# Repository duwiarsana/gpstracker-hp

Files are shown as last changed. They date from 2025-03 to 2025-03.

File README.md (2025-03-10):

# GPS GPRS SMS Tracker

Proyek ini menggunakan **modul GPS dan GPRS (GSM)** secara terpisah untuk mengirimkan koordinat lokasi via SMS ketika menerima perintah dari pengguna. Koding ini dibuat khusus untuk PCB yang sudah dicetak dalam proyek ini.

## 📌 Deskripsi Proyek

Kode ini bekerja dengan membaca data dari modul **GPS** dan mengirimkan koordinat melalui **modul GPRS (GSM)** dalam bentuk link Google Maps. Saat perangkat menerima SMS dengan kata kunci **"LOKASI"**, maka akan membalas dengan tautan lokasi GPS terbaru.

Selain mengirimkan lokasi melalui SMS, proyek ini juga memiliki fitur **panggilan suara**. Jika nomor yang terhubung dengan modul GSM melakukan panggilan ke perangkat ini, maka panggilan akan **otomatis diangkat pada dering ketiga**.

Proyek ini masih berbasis SMS, tetapi jika ingin mengembangkan sistem dengan mengirim data ke **server atau internet**, bisa dilakukan update coding dengan menggunakan **basis data GPRS**.

## 🛠️ Hardware yang Digunakan

- **Mikrokontroler**: Arduino (contoh: Arduino Uno, Nano, atau lainnya)
- **Modul GPS**: Neo-6M atau kompatibel
- **Modul GSM/GPRS**: SIM800L atau SIM900
- **PCB Custom**: Koding ini dibuat untuk PCB khusus yang sudah dirancang agar sesuai dengan proyek ini
- **Kartu SIM** dengan pulsa untuk mengirim SMS dan melakukan panggilan

## 🖇️ **Koneksi Hardware** (Jika Menggunakan Arduino dengan Modul GPS & GSM Terpisah)

Jika kamu menggunakan Arduino tanpa PCB khusus, pastikan koneksi berikut:

### **Modul GPS (Neo-6M)**

| GPS Pin | Arduino Pin |
| --- | --- |
| VCC | 5V |
| GND | GND |
| TX | D3 |
| RX | D2 |

### **Modul GSM (SIM800L/SIM900)**

| GSM Pin | Arduino Pin |
| --- | --- |
| VCC | 5V (Gunakan regulator 4.2V jika perlu) |
| GND | GND |
| TX | D5 |
| RX | D4 |

> **Catatan:** Jika menggunakan PCB khusus yang sudah dicetak, koneksi sudah diatur secara langsung dalam desain PCB, jadi tidak perlu kabel tambahan.

## 🔧 Library yang Digunakan

Sebelum meng-compile kode, pastikan kamu sudah menginstal library berikut di **Arduino IDE**:

- **[TinyGPS++](https://github.com/mikalhart/TinyGPSPlus)** → Untuk membaca data dari GPS
- **SoftwareSerial** (bawaan Arduino) → Untuk komunikasi serial dengan modul GSM & GPS

## ⚙️ Cara Kerja

1. **Perangkat menyala** dan mulai membaca data GPS.
2. Saat menerima SMS dengan isi **"LOKASI"**, perangkat akan mengambil data koordinat dari GPS.
3. Data latitude dan longitude akan diubah menjadi link Google Maps.
4. SMS akan dikirim kembali ke pengirim dengan format: https://maps.google.com/?q=latitude,longitude
5. Nomor pengirim SMS akan disimpan sementara untuk membalas otomatis.
6. Setelah mengirim SMS, perangkat menghapus pesan yang diterima agar memori tidak penuh.
7. Jika ada **panggilan masuk**, perangkat akan **otomatis mengangkat pada dering ketiga**.

## 📌 Cara Menggunakan

1. **Siapkan PCB yang sudah dirakit** dengan Arduino dan modul GPS/GSM.
2. **Masukkan kartu SIM ke modul GSM** (pastikan memiliki pulsa atau paket SMS).
3. **Upload kode ke Arduino** menggunakan Arduino IDE.
4. **Kirim SMS berisi "LOKASI"** ke nomor yang ada di modul GSM.
5. **Perangkat akan membalas dengan link lokasi** berdasarkan data dari modul GPS.
6. **Lakukan panggilan ke nomor SIM pada modul GSM**, dan perangkat akan **mengangkat otomatis pada dering ketiga**.

## 🔥 Troubleshooting

Jika tidak mendapatkan SMS balasan atau koordinat tidak muncul:

- **Cek power supply modul GSM** (SIM800L biasanya butuh minimal 2A agar stabil).
- **Pastikan modul GPS mendapatkan sinyal satelit** (gunakan di luar ruangan untuk tes awal).
- **Gunakan serial monitor** di Arduino IDE untuk melihat output debug.

## 📜 Lisensi

Proyek ini menggunakan lisensi MIT, yang berarti bebas digunakan, dimodifikasi, dan didistribusikan.

---

🚀 Selamat mencoba! Jika ada pertanyaan atau ingin menggunakan PCB khusus ini, silakan hubungi saya.

## 💖 Dukung Pengembangan Proyek Ini

Jika kamu merasa proyek ini bermanfaat dan ingin mendukung pengembangan lebih lanjut, kamu bisa memberikan **donasi melalui Saweria**:

🔗 [https://saweria.co/duwiarsana](https://saweria.co/duwiarsana)  

Terima kasih atas dukungannya! 🤗

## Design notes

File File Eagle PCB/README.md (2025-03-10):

# README FILE EAGLE PCB GPS Tracker Mini

## Deskripsi Proyek
GPS Tracker Mini adalah proyek pelacak GPS berbasis **ATmega328P**, **SIM800C**, dan **Quectel L80 GNSS**. Proyek ini memungkinkan pelacakan lokasi secara real-time dengan komunikasi GSM/GPRS.

### Fitur Utama:
- **Pelacakan GPS:** Menggunakan modul **Quectel L80** untuk mendapatkan koordinat lokasi secara akurat.
- **Koneksi GSM:** Memanfaatkan modul **SIM800C** untuk mengirimkan data lokasi melalui SMS atau server berbasis GPRS.
- **Microcontroller ATmega328P:** Sebagai pusat kendali dari perangkat.
- **Slot MicroSD:** Untuk menyimpan log data lokasi jika koneksi tidak tersedia.
- **Konektor U.FL:** Untuk penggunaan antena eksternal pada modul GSM.

## Skema dan Desain PCB
Desain perangkat ini dibuat menggunakan **Eagle PCB** dan terdiri dari dua file utama:
- **Schematic:** [`GPS TRACKER MINI.sch`](./GPS%20TRACKER%20MINI.sch)
- **PCB Layout:** [`GPS TRACKER MINI.brd`](./GPS%20TRACKER%20MINI.brd)

## Skema Kalau Pakai Arduino Uno dan GPS NEO
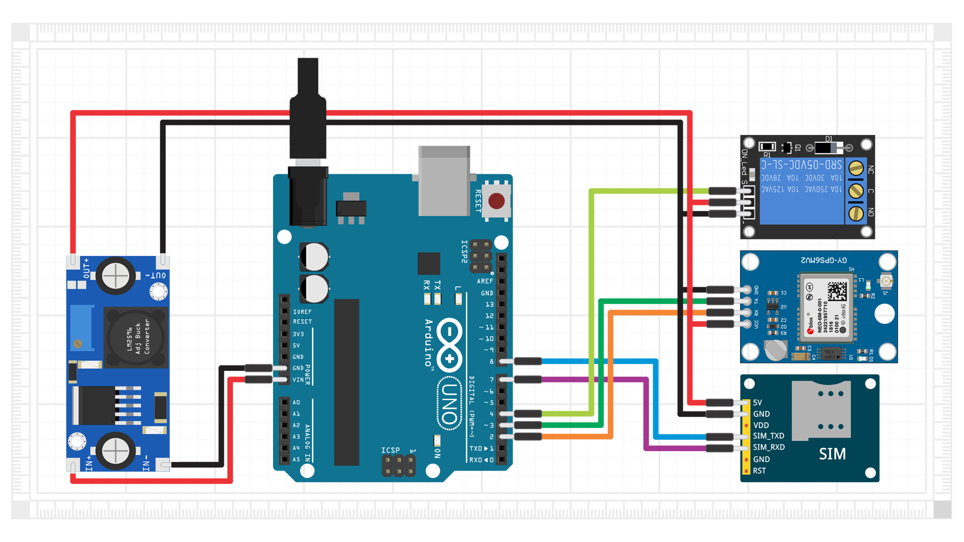
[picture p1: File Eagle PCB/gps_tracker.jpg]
GPS Tracker


## Bill of Materials (BOM)
Berikut adalah daftar komponen utama yang digunakan dalam proyek ini:

| Qty | Value | Device | Package | Parts |
|----|---|---|---|---|
| 1  | ATMEGA328P-MU | ATMEGA328P-MU | QFN-32 | U1 |
| 1  | SIM800C | SIM800C | LCC-42 | U2 |
| 1  | L80_GNSS_MODULE | L80 GNSS Module | Custom | U3 |
| 1  | 4050D | Hex Buffer | SO16 | IC1 |
| 1  | LP298-33 | LDO Regulator 3.3V | SOT23-5L | IC2 |
| 1  | MICROSD | MicroSD Card Slot | MICROSD | X1 |
| 1  | ZD-SOD123 | 5.1V Zener Diode | SOD123 | ZD1 |
| 4  | 0.1uF | Capacitor | C0603 | C3, C15, C19, C21 |
| 2  | 100uF | Capacitor | B/3528-21R | C4, C5 |
| 1  | 10K | Resistor | R0603 | R1 |
| 1  | CSTCE16M0V53MU | Ceramic Resonator 16MHz | CSTCE16M0V53 | Y1 |
| 1  | SIM8051-6-0-14-01-X | Nano SIM Card Connector | SMT | J1 |
| 1  | CON-HIROSE-COAXIAL-U.FL | U.FL Connector | SMT | GSM |
| 1  | LED (Red) | Indicator | LED0805 | ACT |
| 1  | LED (Blue) | Indicator | LED0805 | LED4 |

## Instalasi dan Penggunaan
1. **Flash Firmware** ke ATmega328P menggunakan Arduino IDE atau PlatformIO.
2. **Sambungkan Antena** ke konektor U.FL untuk sinyal GSM lebih baik.
3. **Masukkan Kartu SIM** dan pastikan memiliki paket data aktif.
4. **Gunakan Software** untuk membaca koordinat GPS yang dikirim via SMS atau HTTP POST.

## Pemesanan PCB & Donasi
Jika kamu ingin membeli PCB dari proyek ini atau mendukung pengembangannya, silakan hubungi saya melalui WhatsApp:  
📲 **[085738244251](https://wa.me/6285738244251)**

Atau bisa juga berdonasi melalui:  


## Lisensi
Proyek ini berlisensi **MIT License**, artinya bebas digunakan dan dimodifikasi, namun tetap mencantumkan atribusi kepada pembuat asli.

---
Jika ada pertanyaan atau saran, jangan ragu untuk menghubungi saya melalui GitHub atau media sosial lainnya!

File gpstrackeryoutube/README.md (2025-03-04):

# GPS GPRS SMS Tracker - Arduino Code

Dokumentasi ini menjelaskan bagaimana menggunakan koding dalam folder ini untuk proyek **GPS GPRS SMS Tracker**. Koding ini dirancang untuk bekerja dengan **modul GPS dan GSM (GPRS) secara terpisah**, serta dibuat khusus untuk PCB yang sudah dirancang dalam proyek ini.

## 📌 Persyaratan Software

Untuk menjalankan koding ini, kamu memerlukan software berikut:

1. **[Arduino IDE](https://www.arduino.cc/en/software)** - Untuk mengedit dan mengupload kode ke mikrokontroler.
2. **Driver CH340/CP2102** (jika menggunakan Arduino clone) - Sesuaikan dengan jenis mikrokontroler yang digunakan.
3. **Library Arduino yang dibutuhkan**:
   - [TinyGPS++](https://github.com/mikalhart/TinyGPSPlus) → Untuk membaca data GPS.
   - SoftwareSerial (bawaan Arduino) → Untuk komunikasi serial dengan modul GSM & GPS.

## ⚙️ Cara Menggunakan Koding Ini

1. **Buka Arduino IDE** dan pastikan board yang digunakan sudah terdeteksi.
2. **Instal Library yang Dibutuhkan**
   - Buka **Sketch** > **Include Library** > **Manage Libraries**
   - Cari dan instal **TinyGPS++**
3. **Hubungkan Arduino ke PC** menggunakan kabel USB.
4. **Sesuaikan Koneksi Hardware** jika tidak menggunakan PCB custom (lihat tabel koneksi di README utama).
5. **Upload kode ke Arduino**:
   - Pilih board yang sesuai (**Tools > Board > Arduino Uno/Nano/etc**).
   - Pilih port serial yang sesuai (**Tools > Port > COMx**).
   - Klik tombol **Upload** (ikon panah kanan di Arduino IDE).
6. **Buka Serial Monitor** (Baudrate 9600) untuk melihat log proses komunikasi.
7. **Uji dengan SMS**
   - Kirim SMS berisi **"LOKASI"** ke nomor kartu SIM yang ada di modul GSM.
   - Jika berhasil, akan menerima SMS balasan berupa link Google Maps.
8. **Uji dengan Panggilan**
   - Lakukan panggilan ke nomor SIM dalam modul GSM.
   - Perangkat akan **mengangkat otomatis pada dering ketiga**.

## 🔥 Troubleshooting

- **GPS tidak mendapatkan sinyal?**
  - Pastikan antena GPS terpasang dengan benar.
  - Coba uji di area terbuka untuk mendapatkan sinyal lebih cepat.

- **GSM tidak mengirim atau menerima SMS?**
  - Cek apakah kartu SIM memiliki pulsa atau paket SMS aktif.
  - Pastikan koneksi antara Arduino dan modul GSM sudah benar.

- **Tidak bisa upload kode?**
  - Cek apakah driver CH340/CP2102 sudah terinstal.
  - Coba gunakan kabel USB yang berbeda.

## 📜 Lisensi

Kode ini menggunakan lisensi MIT, artinya bebas digunakan dan dimodifikasi. Jika kamu ingin menggunakan atau mengembangkan proyek ini lebih lanjut, silakan!

🚀 Selamat mencoba!

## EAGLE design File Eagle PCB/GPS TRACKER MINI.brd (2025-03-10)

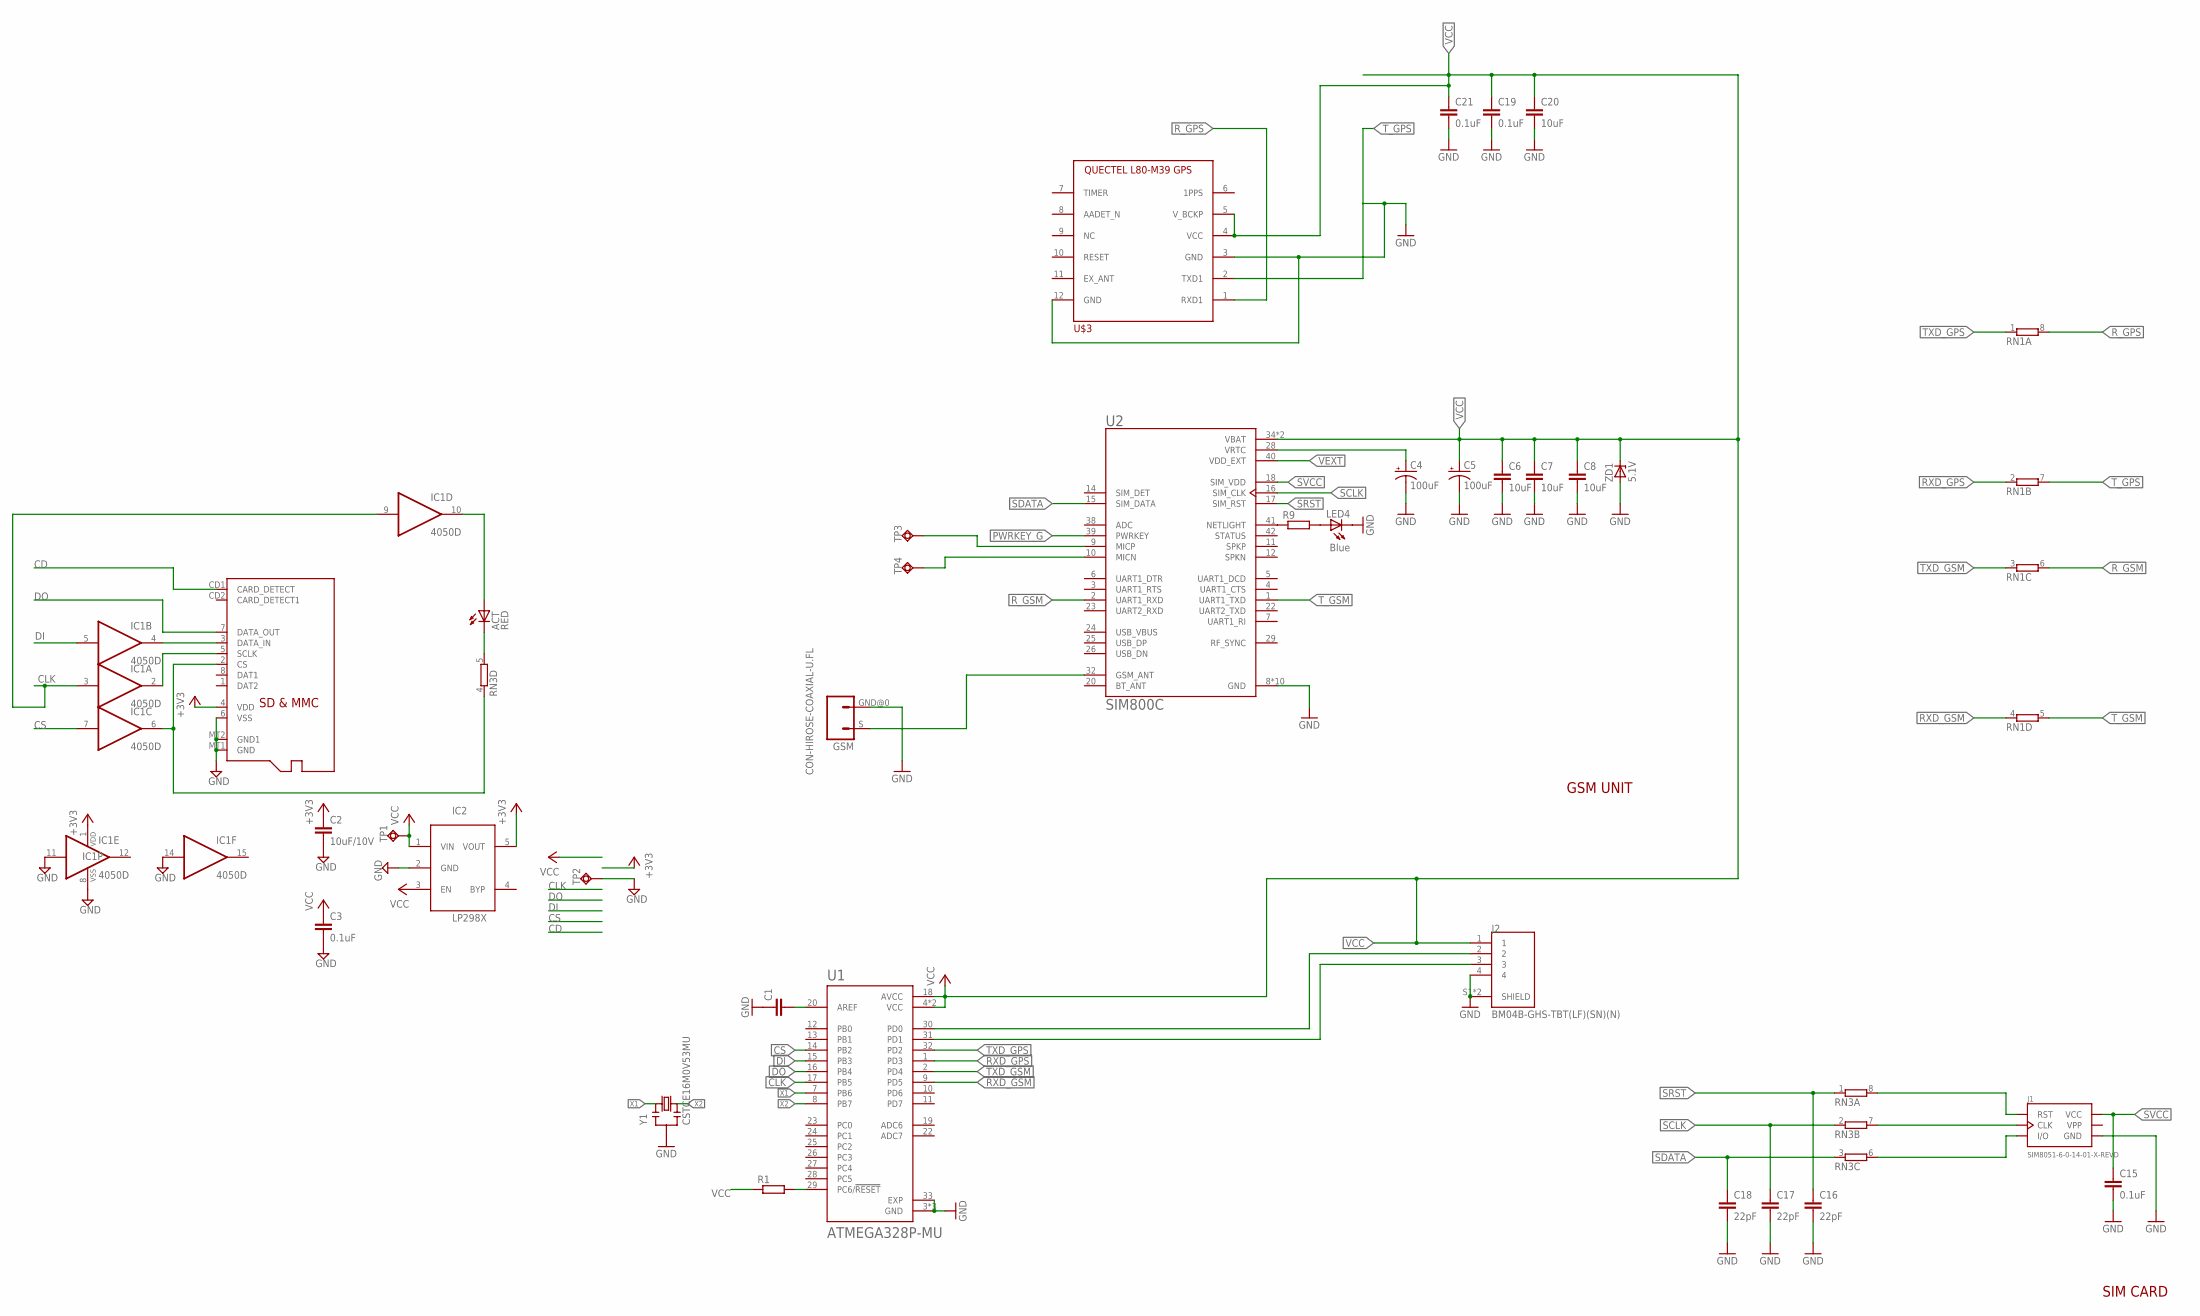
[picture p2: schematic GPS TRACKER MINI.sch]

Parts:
ACT: RED; CHIP-LED0805
C1: C-EUC0603K; C0603K
C2: 10uF/10V; C0603
C3, C15, C19, C21: 0.1uF; C0603
C4, C5: 100uF; B/3528-21R
C6, C7, C8, C20: 10uF; C0603
C16, C17, C18: 22pF; C0603
GSM: CON-HIROSE-COAXIAL-U.FL; CON-U.FL
IC1: 4050D; SO16
IC2: LP298XS; SOT23-5L
J1: SIM8051-6-0-14-01-X-REVD; GCT_SIM8051-6-0-14-01-X-REVD
J2: BM04B-GHS-TBT(LF)(SN)(N); JST_BM04B-GHS-TBT(LF)(SN)(N)
LED4: Blue; CHIP-LED0805
R1, R9: R-EU_R0603; R0603
RN1, RN3: 4R-N0603-ARC; 0603-ARC
TP1, TP2: TPSQTP20R; TP20R
TP3, TP4: TPSQTP14R; TP14R
U1: ATMEGA328P-MU; QFN50P500X500X100-33N
U2: SIM800C; LCC110P1570X1760X250-42N
U$3: L80_GNSS_MODULE; L80_PACKAGE
X1: MICROSD
Y1: CSTCE16M0V53MU; CSTCE16M0V53
ZD1: 5.1V; SOD123

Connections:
+3V3: C2.1, IC1.1 (VDD), IC2.5 (VOUT), X1.4 (VDD)
CD: X1.CD1 (CARD_DETECT)
CLK: IC1.3 (I), IC1.9 (I), U1.17 (PB5)
CS: IC1.7 (I), U1.14 (PB2)
DI: IC1.5 (I), U1.15 (PB3)
DO: U1.16 (PB4), X1.7 (DATA_OUT)
GND: C1.1, C2.2, C3.2, C4.-, C5.-, C6.2, C7.2, C8.2, C15.2, C16.2, C17.2, C18.2, C19.2, C20.2, C21.2, GSM.GND@0 (2), IC1.8 (VSS), IC1.11 (I), IC1.14 (I), IC2.2 (GND), J1.C5 (GND), J2.4, J2.S1 (SHIELD), J2.S2 (SHIELD), LED4.C, TP2.TP, U1.3 (GND), U1.5 (GND), U1.21 (GND), U1.33 (EXP), U2.8 (GND), U2.13 (GND), U2.19 (GND), U2.21 (GND), U2.27 (GND), U2.30 (GND), U2.31 (GND), U2.33 (GND), U2.36 (GND), U2.37 (GND), U$3.3 (GND), U$3.12 (GND), X1.6 (VSS), X1.MT1 (GND), X1.MT2 (GND1), Y1.2, ZD1.A
unnamed: ACT.A, IC1.10 (O)
unnamed: C1.2, U1.20 (AREF)
unnamed: IC1.2 (O), X1.5 (SCLK)
unnamed: IC1.6 (O), RN3.4 (1), X1.2 (CS)
unnamed: ACT.C, RN3.5 (2)
unnamed: IC1.4 (O), X1.3 (DATA_IN)
unnamed: R9.1, U2.41 (NETLIGHT)
unnamed: LED4.A, R9.2
unnamed: J2.2, U1.30 (PD0)
unnamed: J2.3, U1.31 (PD1)
unnamed: TP3.TP, U2.9 (MICP)
unnamed: TP4.TP, U2.10 (MICN)
unnamed: R1.2, U1.29 (PC6/!RESET)
unnamed: C4.+, U2.28 (VRTC)
unnamed: GSM.S (1), U2.32 (GSM_ANT)
unnamed: J1.C2 (RST), RN3.8 (2)
unnamed: J1.C3 (CLK), RN3.7 (2)
unnamed: J1.C7 (I/O), RN3.6 (2)
PWRKEY_G: U2.39 (PWRKEY)
RXD_GPS: RN1.2 (1), U1.1 (PD3)
RXD_GSM: RN1.4 (1), U1.9 (PD5)
R_GPS: RN1.8 (2), U$3.1 (RXD1)
R_GSM: RN1.6 (2), U2.2 (UART1_RXD)
SCLK: C17.1, RN3.2 (1), U2.16 (SIM_CLK)
SDATA: C18.1, RN3.3 (1), U2.15 (SIM_DATA)
SRST: C16.1, RN3.1, U2.17 (SIM_RST)
SVCC: C15.1, J1.C1 (VCC), U2.18 (SIM_VDD)
TXD_GPS: RN1.1, U1.32 (PD2)
TXD_GSM: RN1.3 (1), U1.2 (PD4)
T_GPS: RN1.7 (2), U$3.2 (TXD1)
T_GSM: RN1.5 (2), U2.1 (UART1_TXD)
VCC: C3.1, C5.+, C6.1, C7.1, C8.1, C19.1, C20.1, C21.1, IC2.1 (VIN), IC2.3 (EN), J2.1, R1.1, TP1.TP, U1.4 (VCC), U1.6 (VCC), U1.18 (AVCC), U2.34 (VBAT), U2.35 (VBAT), U$3.4 (VCC), U$3.5 (V_BCKP), ZD1.C
VEXT: U2.40 (VDD_EXT)
VPP: J1.C6 (VPP)
X1: U1.7 (PB6), Y1.1
X2: U1.8 (PB7), Y1.3

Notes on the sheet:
GSM UNIT
SIM CARD

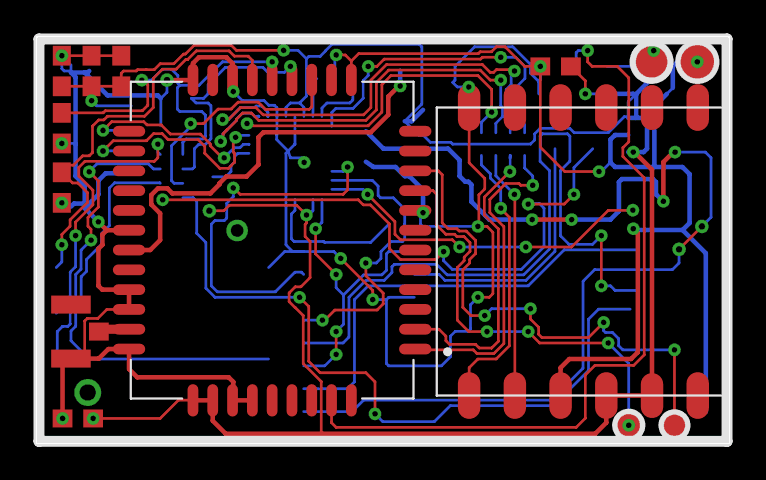
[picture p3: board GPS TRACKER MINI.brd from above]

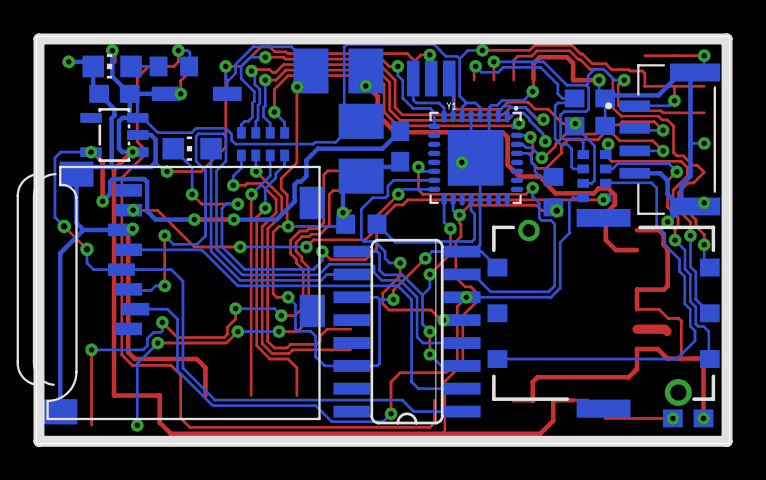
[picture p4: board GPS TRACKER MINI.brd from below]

Board: 2 copper layers, 38.5 x 22.6 mm, 36 parts (22 on the bottom side), 39 nets.

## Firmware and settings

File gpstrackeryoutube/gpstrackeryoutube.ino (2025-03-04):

#include <SoftwareSerial.h>
#include <TinyGPS++.h>

// Deklarasi komunikasi serial untuk GPRS dan GPS
SoftwareSerial GPRS(5, 4);
SoftwareSerial GPS(3, 2);
TinyGPSPlus G;

// Variabel untuk menyimpan data sementara
String sementara = "";
String lati = "";
String longi = "";

void setup() {
  delay(5000); // Delay awal untuk memastikan perangkat siap
  
  // Memulai komunikasi serial dengan modul GPRS dan GPS
  GPRS.begin(9600);
  GPS.begin(9600);
  Serial.begin(9600);

  Serial.println("Lewat");
  delay(10);
  
  // Mengatur parameter GPRS
  GPRS.print("ATS0=3\r\n");
  delay(100);
  GPRS.print("AT+CMGF=1\r\n"); // Mengatur mode teks untuk SMS
  delay(1000);
  GPRS.print("AT+CNMI=2,2,0,0,0\r\n"); // Mengatur notifikasi pesan masuk
  delay(1000);
}

void loop() {
  GPRS.listen(); // Mengaktifkan komunikasi dengan GPRS
  
  while (GPRS.available() > 0) {
    String incoming = GPRS.readStringUntil('\n'); // Membaca pesan dari GPRS
    incoming.trim();
    Serial.println("sms = " + incoming);
    
    // Mengekstrak nomor pengirim jika ada pesan masuk
    if (incoming.startsWith("+CMT:")) {
      String senderNumber = extractPhoneNumber(incoming);
      sementara = senderNumber;
      Serial.println("Nomor Pengirim: " + senderNumber);
    }
    
    // Jika pesan mengandung kata "LOKASI", kirim koordinat GPS
    if (incoming.indexOf("LOKASI") >= 0) {
      smartDelay(5000); // Mengambil data GPS terbaru
      
      String pesan = "https://maps.google.com/?q=" + lati + "," + longi;
      sendSMS(sementara.c_str(), pesan.c_str()); // Mengirim SMS dengan lokasi
      delay(100);
      GPRS.println("AT+CMGD=1,4"); // Menghapus semua SMS di modul GPRS
      delay(1000);
    }
  }
}

// Fungsi untuk mengirim SMS
void sendSMS(const char* phoneNumber, const char* message) {
  GPRS.println("AT+CMGF=1"); // Mengatur SMS ke mode teks
  delay(2000);

  GPRS.print("AT+CMGS=\"");
  GPRS.print(phoneNumber);
  GPRS.println("\"");
  delay(1000);

  GPRS.print(message);
  delay(1000);

  GPRS.write(26); // Mengirim karakter CTRL+Z untuk mengakhiri SMS
  delay(5000);

  Serial.println(message);
}

// Fungsi untuk mengekstrak nomor telepon dari pesan SMS
String extractPhoneNumber(String sms) {
  int firstQuote = sms.indexOf('"') + 1;
  int secondQuote = sms.indexOf('"', firstQuote);
  return sms.substring(firstQuote, secondQuote);
}

// Fungsi untuk menunggu dan membaca data GPS dalam waktu tertentu
static void smartDelay(unsigned long ms) {
  unsigned long start = millis();
  do {
    GPS.listen();
    delay(2);
    while (GPS.available()) {
      G.encode(GPS.read());
    }
  } while (millis() - start < ms);
  
  lati = String(G.location.lat(), 8); // Mengambil data latitude
  longi = String(G.location.lng(), 6); // Mengambil data longitude
  
  Serial.println(lati);
  Serial.println(longi);
}

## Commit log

2025-03-04 Update gpstrackeryoutube.ino
    Menambahkan keterangan coding dan mengubah pin komunikasi sesuai dengan design PCB
2025-03-10 Menambahkan file design EAGLE PCB
    [GPS TRACKER MINI.brd, GPS TRACKER MINI.sch]
2025-03-10 Update README.md
    menambahkan gambar rangkaian kalau menggunakan arduino

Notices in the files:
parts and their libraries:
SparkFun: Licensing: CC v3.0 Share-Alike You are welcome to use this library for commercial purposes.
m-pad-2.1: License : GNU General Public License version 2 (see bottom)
